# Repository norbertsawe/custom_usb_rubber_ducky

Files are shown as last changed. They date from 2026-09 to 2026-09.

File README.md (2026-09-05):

# Nodus — RP2040 Custom USB Keystroke Injection Platform






**Nodus** is a custom, ultra-compact USB Human Interface Device (HID) platform designed for keystroke injection, automated penetration testing, and security research. Powered by the Raspberry Pi RP2040 microcontroller, the board features dedicated high-speed QSPI flash memory, a precision external crystal oscillator for reliable USB PHY timing, and hardware physical controls for rapid reset and bootloader recovery.

---

## 📷 Board Hardware Overview

The PCB is custom designed in a standard USB stick form factor with an integrated PCB USB-A plug:

<p align="center">
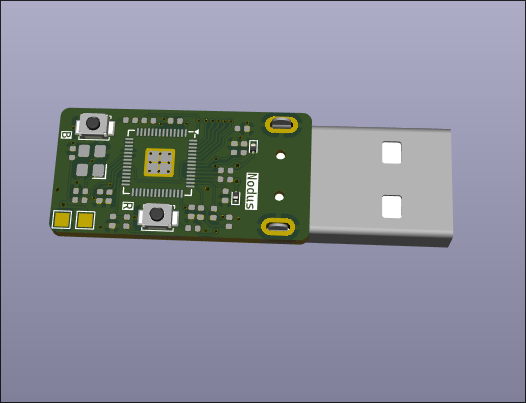
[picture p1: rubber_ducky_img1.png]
Board View 1
  
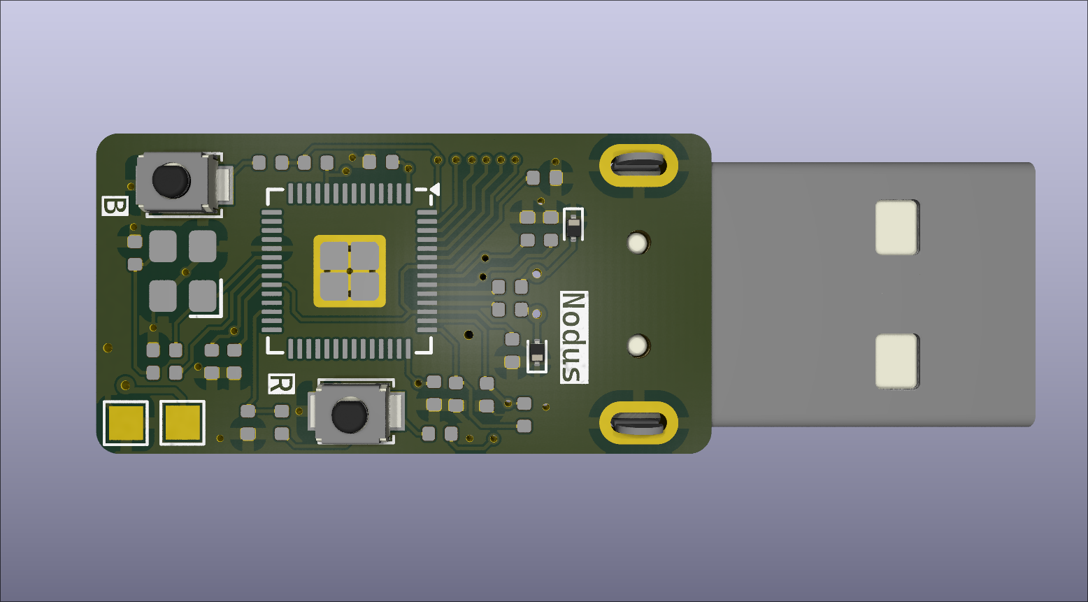
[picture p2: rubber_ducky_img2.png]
Board View 2
  
</p>

<p align="center">
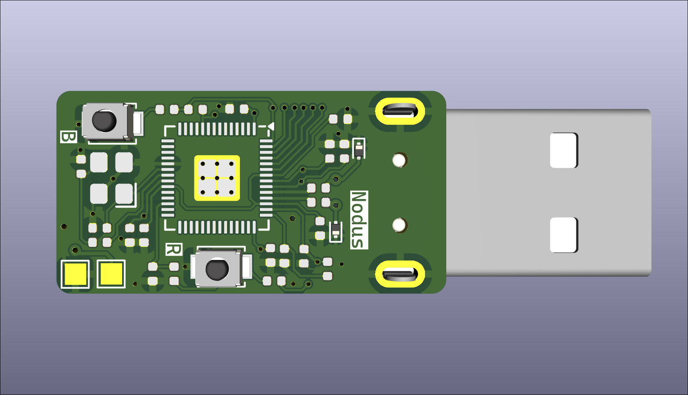
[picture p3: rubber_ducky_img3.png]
Board View 3
  
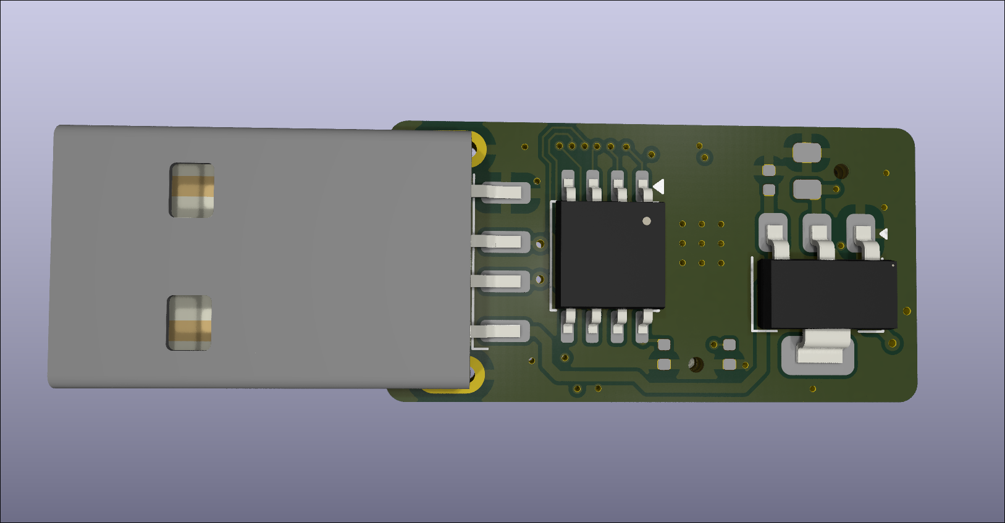
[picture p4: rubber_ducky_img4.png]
Board View 4
  
</p>

### Key Hardware Features

* **Microcontroller:** Raspberry Pi RP2040 Dual-Core ARM Cortex-M0+ running up to 133 MHz.
* **Storage:** High-speed QSPI NOR Flash IC for payload scripts and custom firmware storage.
* **Clock Source:** External 12 MHz Crystal Oscillator ensuring strict USB 2.0 full-speed timing stability.
* **On-Board Controls:**
  * **`B` (BOOTSEL):** Physical tactile button to force UF2 bootloader mode upon startup.
  * **`R` (RESET):** Hardware reset button for fast rebooting and rapid payload re-execution cycles without unplugging the drive.
* **Form Factor:** Slim, low-profile SMT design tailored for standard custom USB flash drive enclosures.

---

## 📊 Technical Specifications

| Component | Specification / Notes |
| :--- | :--- |
| **Core Processor** | RP2040 (Dual ARM Cortex-M0+, 264KB SRAM) |
| **Clock Source** | 12.000 MHz SMD Crystal Oscillator ($\pm$20 ppm) |
| **Flash Memory** | External QSPI NOR Flash (W25Qxx series or equivalent) |
| **Interface** | USB 2.0 Full-Speed (12 Mbps) Male USB-A Connector |
| **Power Supply** | 5V VBUS regulated via low-dropout (LDO) regulator to 3.3V |
| **Status Indicators** | Configurable User/Status LED(s) |
| **Debug & Control** | Tactical Boot/Reset switches, SWD target pads |

---

## 📁 Repository Structure

```

.
├── Hardware/            # KiCad schematics (.kicad_sch), PCB layouts (.kicad_pcb), and Gerber outputs
├── README.md            # Project overview and instructions
├── rubber_ducky_img1.png
├── rubber_ducky_img2.png
├── rubber_ducky_img3.png
└── rubber_ducky_img4.png

```

---

## 🚀 Quickstart & Hardware Testing

### 1. Putting the Board into Bootloader Mode
1. Plug the Nodus device into a host computer USB port.
2. Hold down the **`B` (BOOTSEL)** button and press the **`R` (RESET)** button once (or plug the device in while holding **`B`**).
3. Release the **`B`** button.
4. The device will enumerate as an external mass storage drive named `RPI-RP2`.

---

## 🛠 Firmware Development (WIP)

> [!NOTE]
> **Work In Progress:** Custom payload engines and dedicated firmware drivers are currently under active development. Hardware architecture and memory configurations are finalized.

Target build process once the C/C++ SDK engine is integrated:

```bash
cd Firmware
mkdir build && cd build
cmake ..
make -j$(nproc)

```

---

> [!WARNING]
> **Security & Usage Disclaimer**
> This hardware platform is intended exclusively for authorized security auditing, educational purposes, penetration testing, and legitimate research activities. Always obtain explicit written permission from system owners before testing or running payloads on any host environment.

---

## 📜 License

This project is licensed under the MIT License. See the `LICENSE` file for details.

```

```

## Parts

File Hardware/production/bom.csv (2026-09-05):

Designator | Footprint | Quantity | Value | LCSC Part #
C1, C18, C2, C3, C4, C44, C5, C6, C7 | C_0402 | 9 | 100nF | C1525
C10, C11, C17, C9 | C_0402 | 4 | 2.2uF | C12530
C13 | C_0402 | 1 | 1uF | C52923
C14 | C_0805 | 1 | 47uF | C16780
C15, C16 | C_0402 | 2 | 15pF | C1548
D1, D2 | D_SOD-923 | 2 | ESD9B3.3ST5G
J2 | USB_A_CNCTech_1001-011-01101_Horizontal | 1 | USB_A
R1 | R_0402 | 1 | 200Ω | C25087
R10 | R_0402 | 1 | 10kΩ | C25744
R11 | R_0402 | 1 | 27kΩ | C25771
R2, R3 | R_0402 | 2 | 27Ω | C25092
R6, R8 | R_0402 | 2 | 1kΩ | C11702
SW1, SW2 | SW_SPST_B3U-1000P-B | 2 | SW_Push
TP1, TP2 | TestPoint_Pad_1.5x1.5mm | 2 | TestPoint
U1 | QFN-56-1EP_7x7mm_P0.4mm_EP3.2x3.2mm_ThermalVias | 1 | RP2040 | C2040
U2 | SOT-223-3_TabPin2 | 1 | AMS1117-3.3
U3 | OSC-SMD_4P-L3.2-W2.5-BL | 1 | ABM8-272-T3_C20625731 | C20625731
U4 | SOIC-8_5.3x5.3mm_P1.27mm | 1 | W25Q128JVS

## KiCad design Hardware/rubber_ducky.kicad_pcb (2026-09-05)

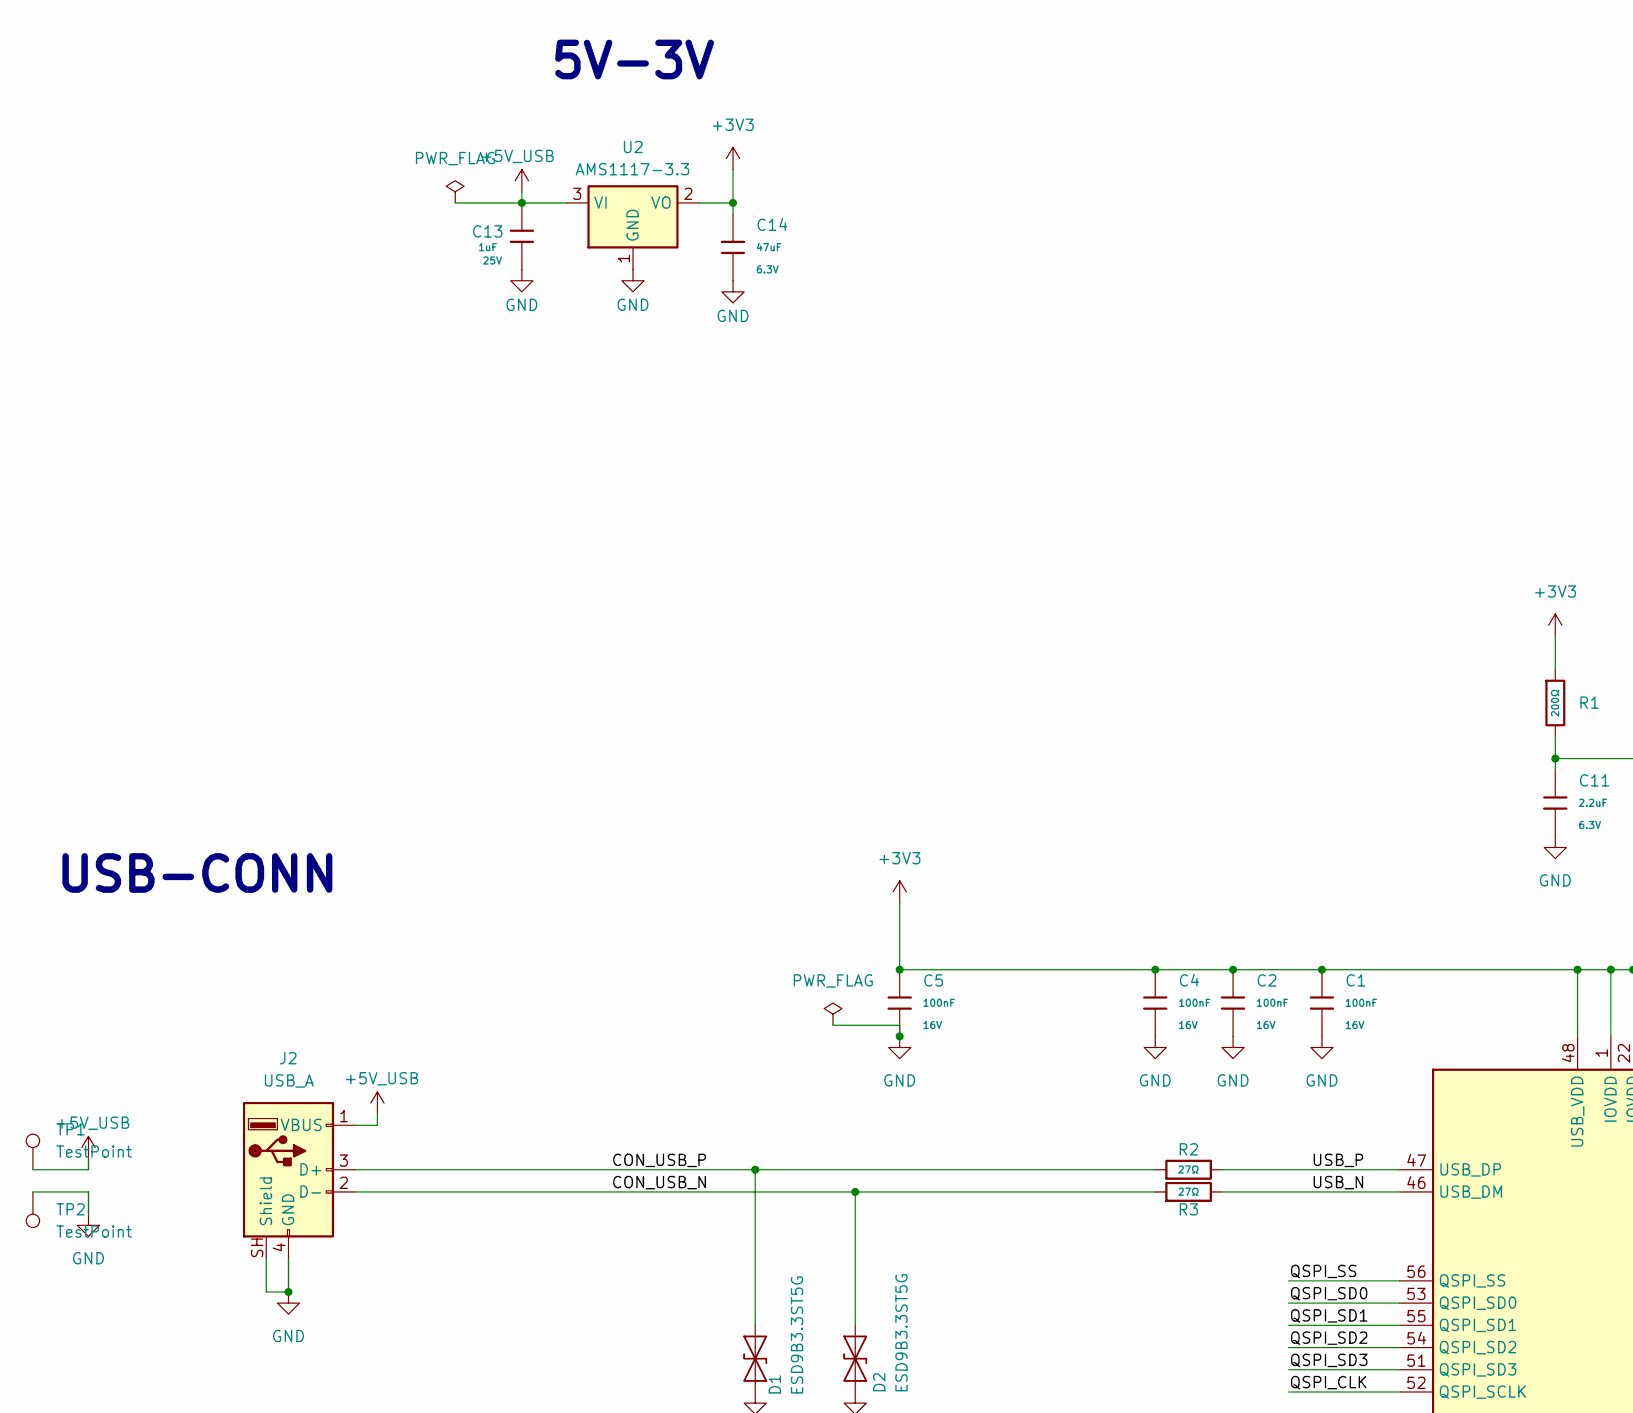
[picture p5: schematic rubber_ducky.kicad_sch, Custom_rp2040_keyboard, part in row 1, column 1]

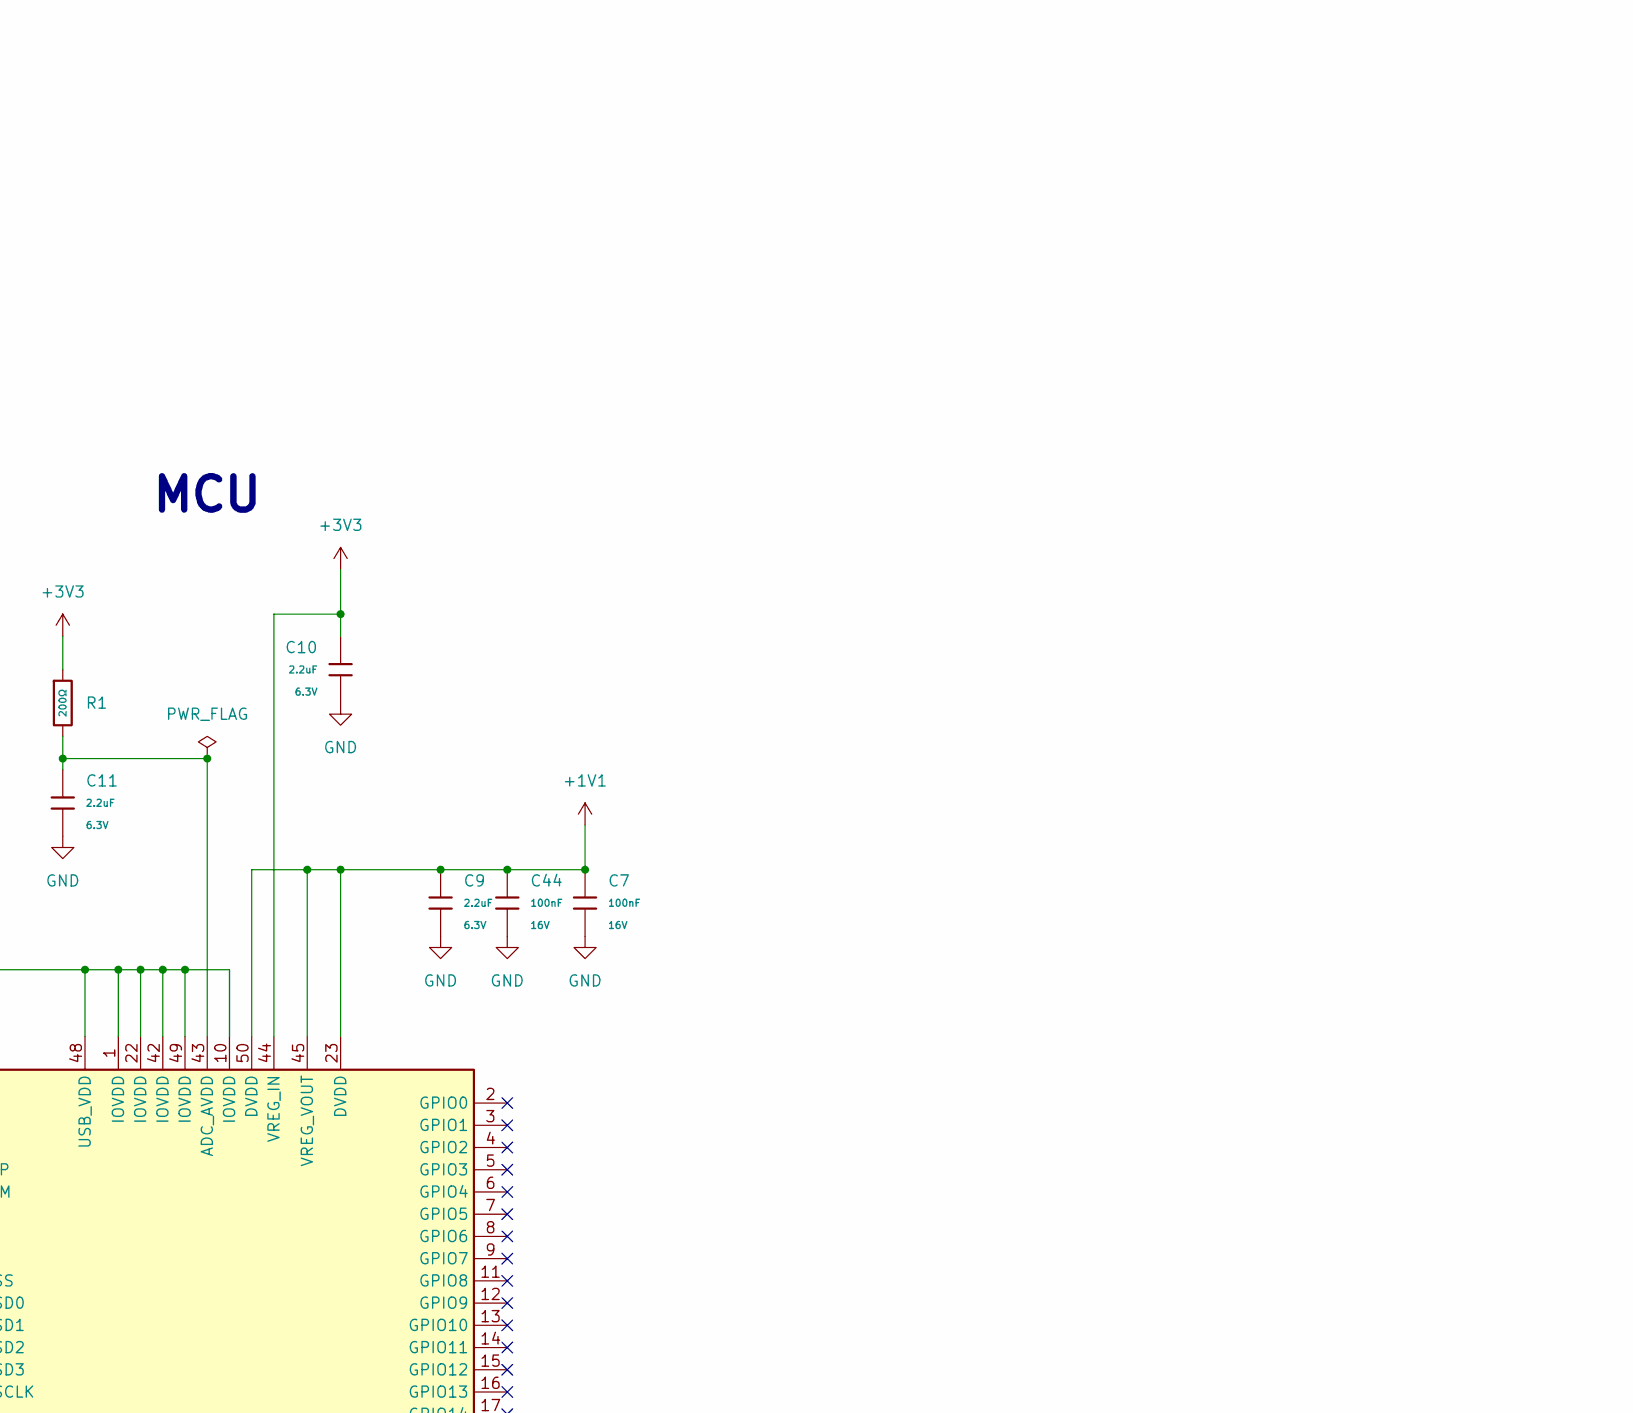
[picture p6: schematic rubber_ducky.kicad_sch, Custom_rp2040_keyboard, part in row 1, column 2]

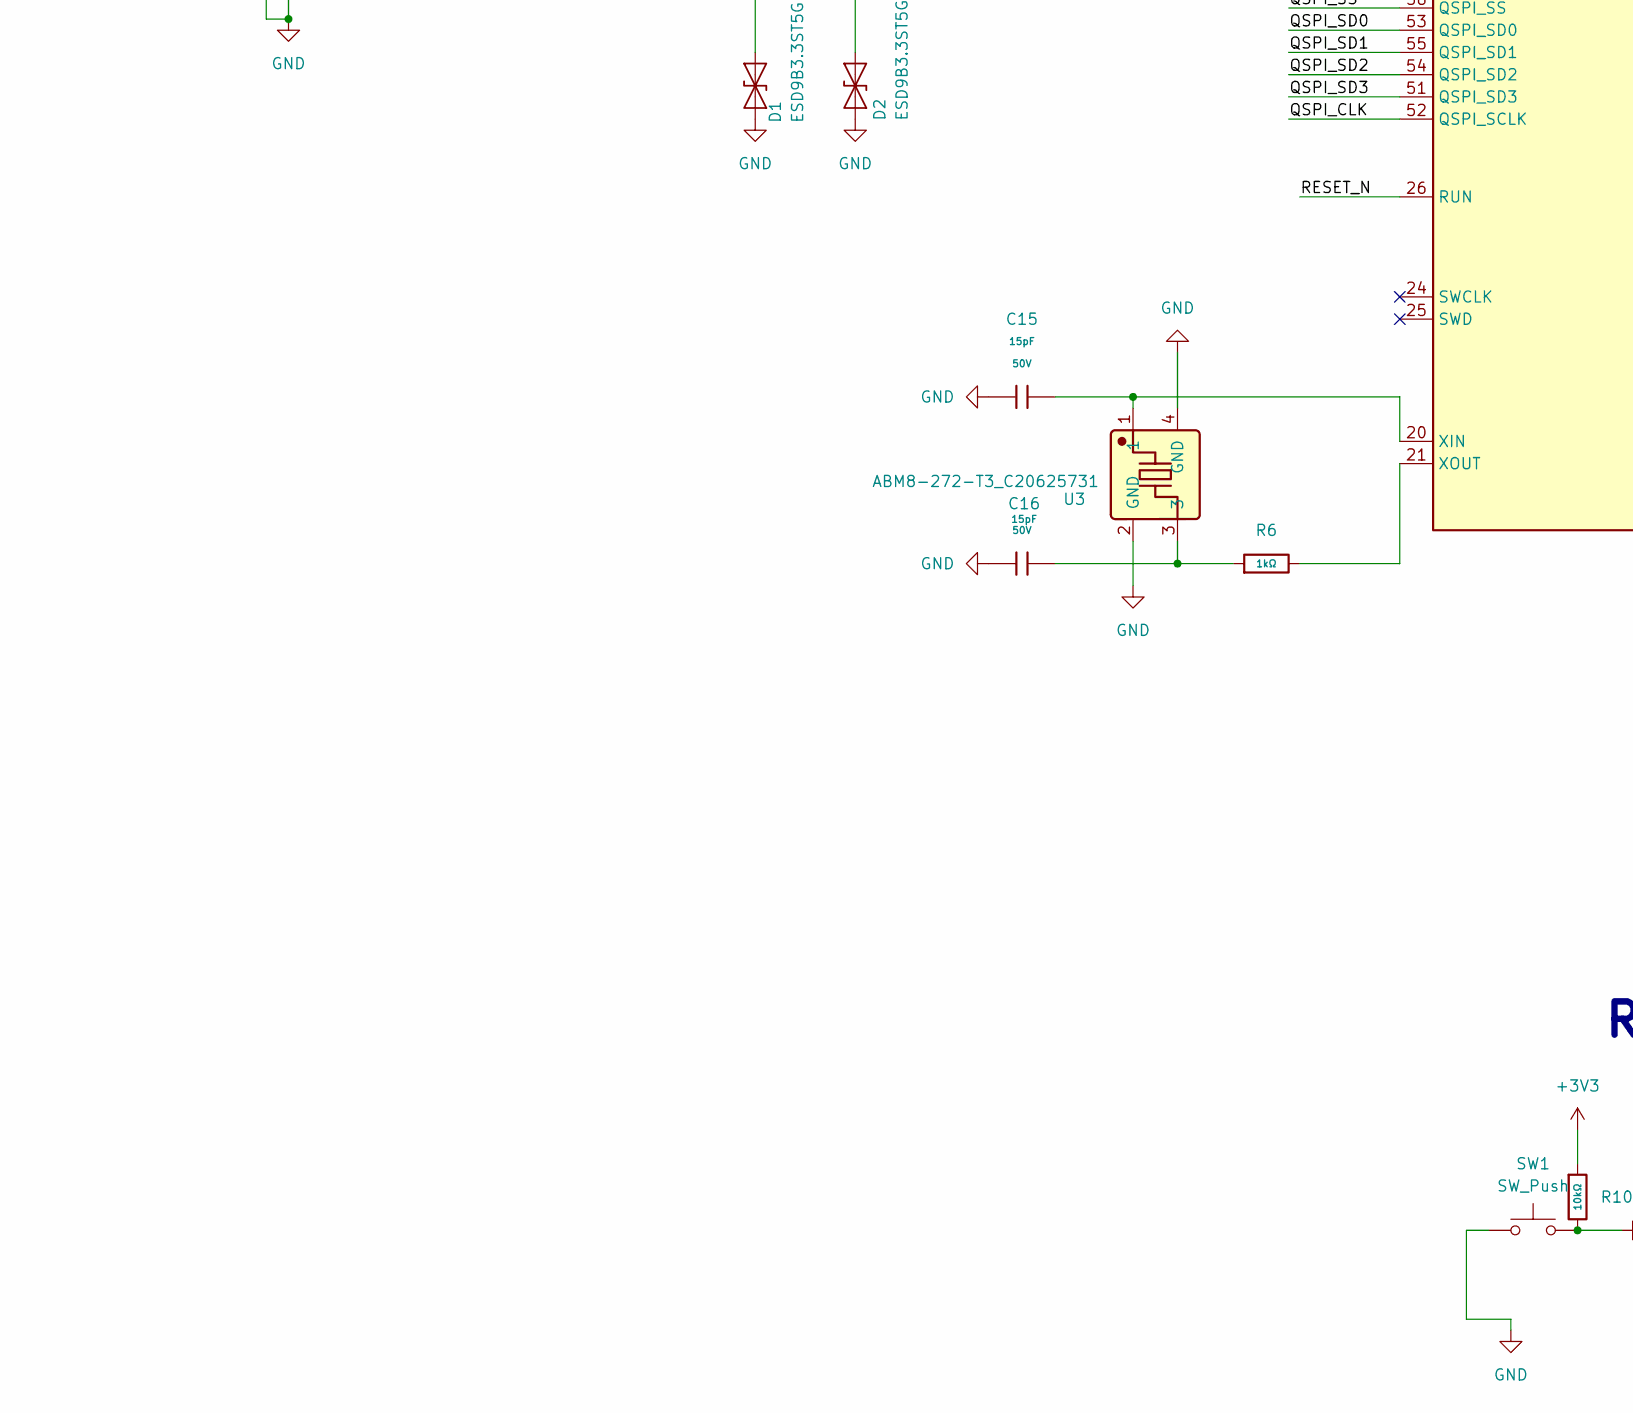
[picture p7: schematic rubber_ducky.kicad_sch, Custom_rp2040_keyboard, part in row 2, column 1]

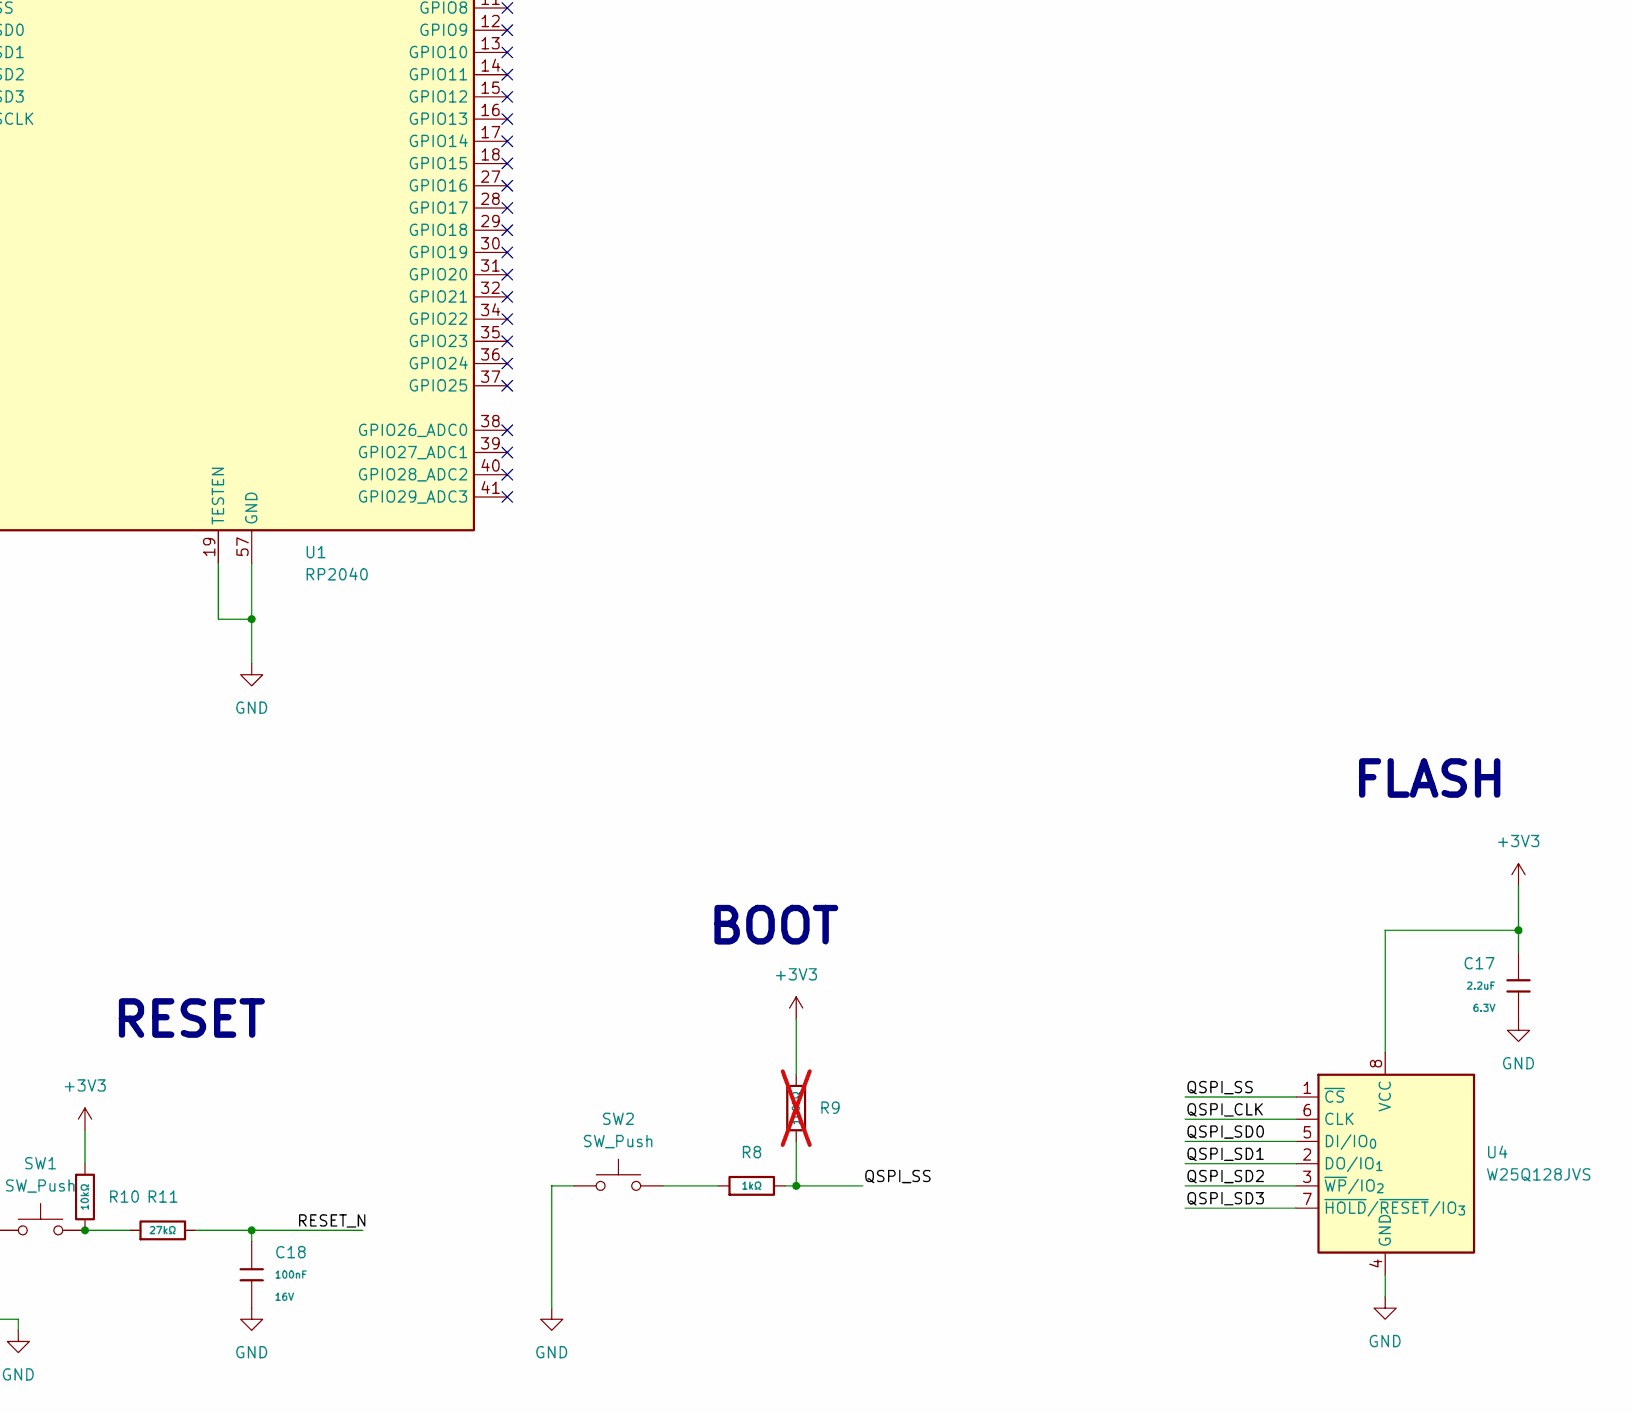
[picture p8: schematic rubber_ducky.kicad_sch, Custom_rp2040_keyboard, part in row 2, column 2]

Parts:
C1, C2, C4, C5, C7, C18, C44: 100nF; C_0402; Voltage Rated 16V; Tolerance ±10%; Part CL05B104KO5NNNC; LCSC C1525
C9, C10, C11, C17: 2.2uF; C_0402; Voltage Rated 6.3V; Tolerance ±20%; Part CL05A225MQ5NSNC; LCSC C12530
C13: 1uF; C_0402; Voltage Rated 25V; Tolerance ±10%; Part CL05A105KA5NQNC; LCSC C52923
C14: 47uF; C_0805; Voltage Rated 6.3V; Tolerance ±20%; Part CL21A476MQYNNNE; LCSC C16780
C15, C16: 15pF; C_0402; Voltage Rated 50V; Tolerance ±5%; Part 0402CG150J500NT; LCSC C1548
D1, D2: ESD9B3.3ST5G; D_SOD-923
J2: USB_A; USB_A_CNCTech_1001-011-01101_Horizontal
R1: 200Ω; R_0402; Overload Voltage (Max) 50V; Tolerance ±1%; Part 0402WGF2000TCE; LCSC C25087
R2, R3: 27Ω; R_0402; Overload Voltage (Max) 50V; Tolerance ±1%; Part 0402WGF220JTCE; LCSC C25092
R6, R8: 1kΩ; R_0402; Overload Voltage (Max) 50V; Tolerance ±1%; Part 0402WGF1001TCE; LCSC C11702
R9: 100kΩ; R_0402; Overload Voltage (Max) 50V; Tolerance ±1%; Part 0402WGF1003TCE; LCSC C25741; not fitted
R10: 10kΩ; R_0402; Overload Voltage (Max) 50V; Tolerance ±1%; Part 0402WGF1002TCE; LCSC C25744
R11: 27kΩ; R_0402; Overload Voltage (Max) 50V; Tolerance ±1%; Part 0402WGF2702TCE; LCSC C25771
SW1, SW2: SW_Push; SW_SPST_B3U-1000P-B
TP1, TP2: TestPoint; TestPoint_Pad_1.5x1.5mm
U1: RP2040; QFN-56-1EP_7x7mm_P0.4mm_EP3.2x3.2mm_ThermalVias; LCSC C2040
U2: AMS1117-3.3; SOT-223-3_TabPin2
U3: ABM8-272-T3_C20625731; OSC-SMD_4P-L3.2-W2.5-BL; Manufacturer Part ABM8-272-T3; LCSC C20625731
U4: W25Q128JVS; SOIC-8_5.3x5.3mm_P1.27mm

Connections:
+1V1: C7.2, C9.1, C44.2, U1.23 (DVDD), U1.45 (VREG_VOUT), U1.50 (DVDD)
+3V3: C1.2, C2.2, C4.2, C5.2, C10.1, C14.1, C17.1, R1.1, R9.1, R10.1, U1.1 (IOVDD), U1.10 (IOVDD), U1.22 (IOVDD), U1.42 (IOVDD), U1.44 (VREG_IN), U1.48 (USB_VDD), U1.49 (IOVDD), U2.2 (VO), U4.8 (VCC); also elsewhere on the board
+5V_USB: C13.1, J2.1 (VBUS), TP1.1 (1_1), U2.3 (VI)
/CON_USB_N: D2.2 (A2), J2.2 (D-), R3.1
/CON_USB_P: D1.2 (A2), J2.3 (D+), R2.1
/QSPI_CLK: U1.52 (QSPI_SCLK), U4.6 (CLK)
/QSPI_SD0: U1.53 (QSPI_SD0), U4.5 (DI/IO_{0})
/QSPI_SD1: U1.55 (QSPI_SD1), U4.2 (DO/IO_{1})
/QSPI_SD2: U1.54 (QSPI_SD2), U4.3 (~WP/IO_{2})
/QSPI_SD3: U1.51 (QSPI_SD3), U4.7 (~HOLD/~RESET/IO_{3})
/QSPI_SS: R8.2, R9.2, U1.56 (QSPI_SS), U4.1 (~CS)
/RESET_N: C18.2, R11.2, U1.26 (RUN)
/USB_N: R3.2, U1.46 (USB_DM)
/USB_P: R2.2, U1.47 (USB_DP)
GND: C1.1, C2.1, C4.1, C5.1, C7.1, C9.2, C10.2, C11.2, C13.2, C14.2, C15.1, C16.1, C17.2, C18.1, C44.1, D1.1 (A1), D2.1 (A1), J2.4 (GND), J2.SH (Shield), SW1.1, SW2.1, TP2.1 (1_1), U1.19 (TESTEN), U1.57 (GND), U2.1 (GND), U3.2 (GND), U3.4 (GND), U4.4 (GND); also elsewhere on the board
unnamed: C16.2, R6.1, U3.3
unnamed: R8.1, SW2.2
unnamed: R10.2, R11.1, SW1.2
unnamed: C11.1, R1.2, U1.43 (ADC_AVDD)
unnamed: C15.2, U1.20 (XIN), U3.1
unnamed: R6.2, U1.21 (XOUT)

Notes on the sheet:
MCU
BOOT
FLASH
USB-CONN
RESET
5V-3V

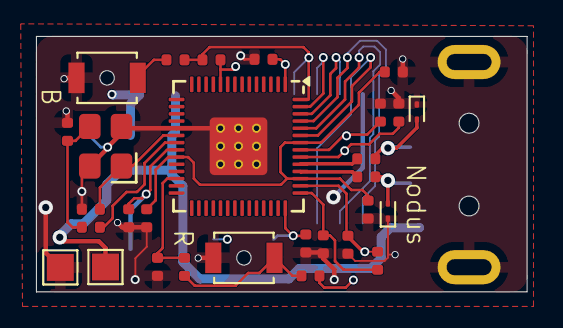
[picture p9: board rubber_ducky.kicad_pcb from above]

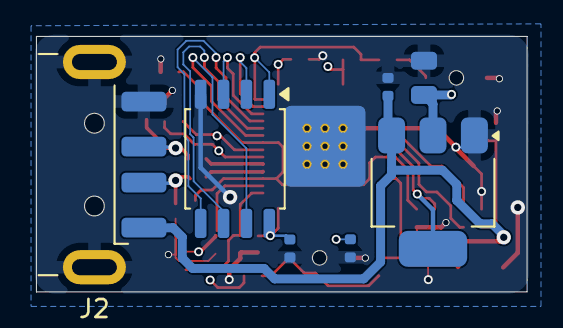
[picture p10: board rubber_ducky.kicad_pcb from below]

Board: 4 copper layers, 27.3 x 14.2 mm, 36 parts (7 on the bottom side), 21 nets.

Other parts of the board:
C3, C6: 100nF; C_0402

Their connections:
+3V3: C3.2, C6.2; also elsewhere on the board
GND: C3.1, C6.1; also elsewhere on the board

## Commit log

2026-09-05 feat: initial commit
    [bom.csv, designators.csv, positions.csv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]
2026-09-05 adding PCB images

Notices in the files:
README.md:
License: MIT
